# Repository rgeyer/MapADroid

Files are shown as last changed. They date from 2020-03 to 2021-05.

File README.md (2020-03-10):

# Description
This is a repository for all of resources that were used to build our local communities Pokemon scanner.

Primarily, this is the Map-A-Droid software, with some minor modifications, a docker compose file for our specific setup, and finally a 3d printed, rack mountable case for holding 16 of the Android TV boxes that are required for scanning.

This is an initial commit of VERY rough notes and resources, expect it to get more refined over time.

# BOM

|Qty|Item|Link|Cost Per|Total|Bulk Total|
|---|----|----|---|-----|---|
|16|A95X F1|https://www.amazon.com/Sawpy-Android-Smart-Quad-core-Cortex-A53/dp/B07PF271DF|$25.99|$415.84|$415.84|
|1|Meanwell 5v PSU|https://www.amazon.com/MEAN-WELL-LRS-350-5-Single-Switchable/dp/B0131V9TG0|$35.92|$35.92|$35.92|
|1|16 Channel 5v Relay Board|https://www.amazon.com/Organizer-16-Channel-Interface-Optocoupler-Arduino/dp/B07Y2X4F77|$13.98|$13.98|$13.98|
|16|DC Power Socket|https://www.amazon.com/gp/product/B01G6EB5U2/|$0.69|$11.04|$13.98|
|16|~1ft Length 22ga Power Wire|https://www.amazon.com/gp/product/B07SLBD1FY/|$0.15|$2.04|$15.00|
|1|Arduino ESP8266 NodeMCU|https://www.amazon.com/gp/product/B07HF44GBT/|$4.00|$4.00|$11.99|
|1|Waveshare Arduino IO Expansion Board 16ch|https://www.amazon.com/dp/B07P2H1NZG/|$7.95|$7.95|$7.95|
|1|1m Strip addressable LEDs|https://www.amazon.com/dp/B01CDTEJR0/|$21.88|$21.88|$21.88|
|1|Power Cable|https://www.amazon.com/gp/product/B01J4M3QDW|$3.59|$3.59|$17.95|
|3|18ga U Terminals|https://www.amazon.com/GFORTUN-Terminals-Insulated-Connector-22-16AWG/dp/B06XV8GLXJ/|$0.07|$0.21|$6.98|
|2|1kg PETG Filament|https://www.amazon.com/gp/product/B07PGYL6SV/|$18.33|$36.66|$54.99|
|2|80mm 5v cooling fan|https://www.amazon.com/dp/B0119SLG18/|$7.01|$14.02|$14.02|
|4|8 Position Dual Row Terminal Strip + Barrier Strip|https://www.amazon.com/dp/B07CLX1VW5/|$1.92|$7.66|$11.49|
|16|1ft Ethernet Patch Cables (CAT5 is fine, but impossible to find)|https://www.amazon.com/dp/B07CXPQ4SX/|$0.95|$15.20|$18.99|
|1|24 Port Ethernet switch|Ebay|~$60|~$60|~$60|
|1|IKEA Lack Side Table|https://www.ikea.com/us/en/p/lack-side-table-black-20011408/|$15|$15|$15|
|||||||
||Totals|||$663.11|$741.84|

# 3D Printed Parts

STLs in the `resources/ATVRackSTLs` directory.

Design 1, before optimization

|Qty|STL|Weight ea.|Weight Total|
|---|---|---|---|
|1|CabCenter|480g|480g|
|1|CabLeft|316g|316g|
|1|CabRight|316g|316g|
|16|Tray|18g|288g|
|2|ATVFrontLidBottom|14g|28g|
|2|ATVRearLidBottom|15g|30g|
|2|ATVFrontLidTop|12g|24g|
|2|ATVRearLidTop|53g|106g|
|1|PSUBracket|42g|42g|
|1|LidCenter|37g|37g|
||||1667g|

|Qty|STL|Weight ea.|Weight Total|Spool Before|Spool After|
|---|---|---|---|---|---|
|1|CabCenter|300g|300g|1240g|1067g|
|1|CabLeft|246g|246g|654g|464g2|
|1|CabRight|246g|246g|||
|16|Tray|9g|144g|||
|2|ATVFrontLidBottom|||||
|2|ATVRearLidBottom|||||
|2|ATVFrontLidTop|||||
|2|ATVRearLidTop|||||
|1|PSUBracket|||||
|1|LidCenter|||||
||||1203g|

# TODO

* Modify RocketMAD to use a public sprite set
  * https://github.com/whitewillem/PogoAssets
  * https://github.com/ZeChrales/PogoAssets

* Scheduled Maintenance
  * DB
    * (actually delete) select count(*) from pokemon where last_modified < DATE_SUB(NOW(), INTERVAL 72 HOUR);

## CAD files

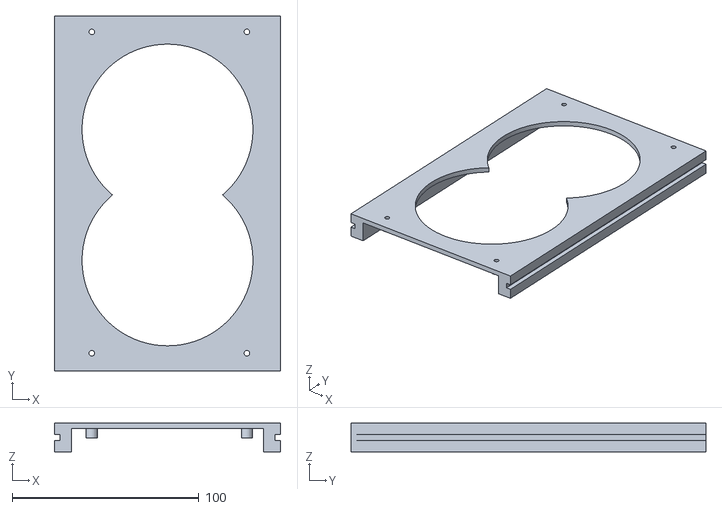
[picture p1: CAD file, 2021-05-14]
resources/ATVRackSTLs/RelayTray.stl
121.0 x 190.0 x 15.4

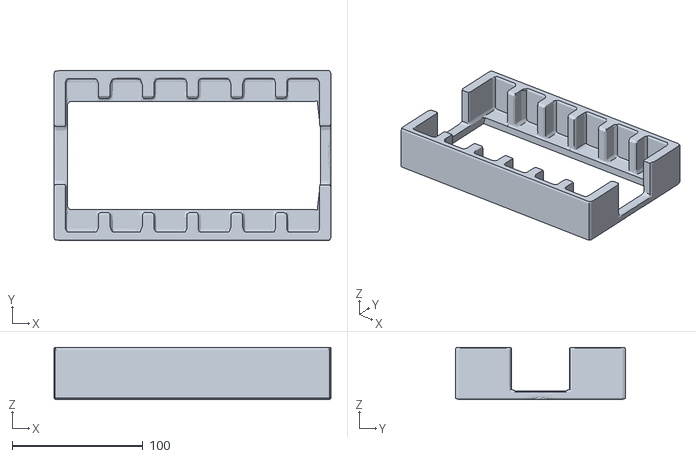
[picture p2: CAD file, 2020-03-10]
resources/atvstandf1.stl
212.2 x 130.4 x 40.0

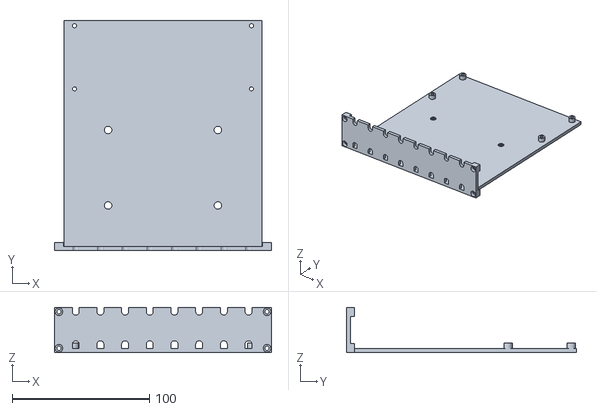
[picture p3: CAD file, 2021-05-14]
resources/ATVRackSTLs/BottomTerminalBlockTrayWith8chRelay.stl
158.2 x 168.0 x 33.2

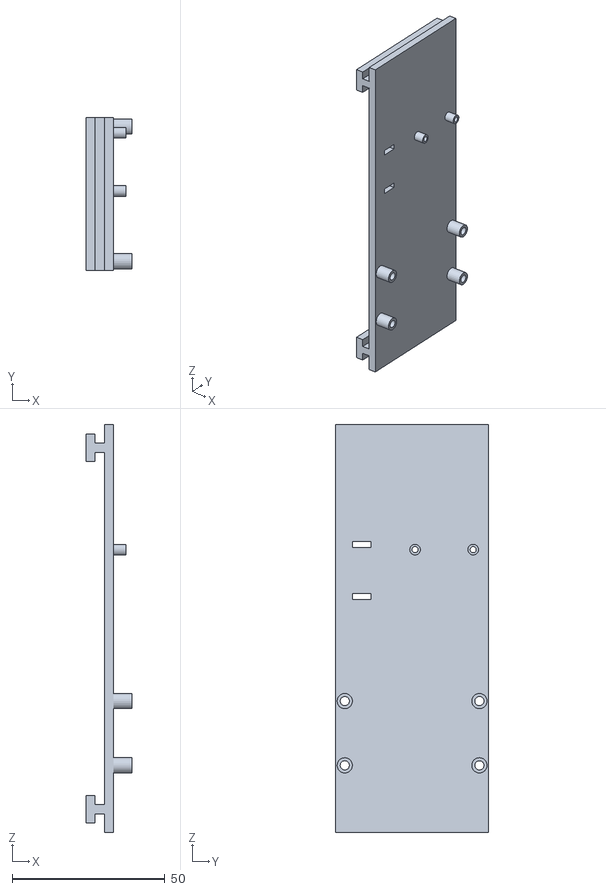
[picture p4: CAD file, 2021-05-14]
resources/ATVRackSTLs/IOBracketExternal.stl
15.1 x 50.0 x 133.4

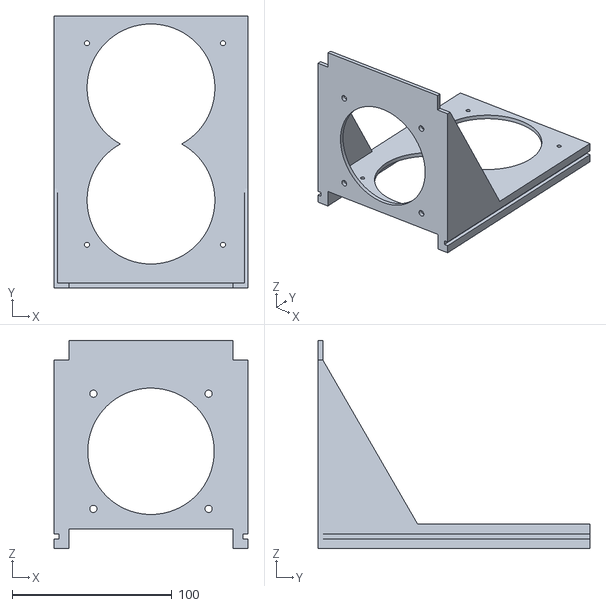
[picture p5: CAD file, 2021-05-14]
resources/ATVRackSTLs/200wPSUTray.stl
121.0 x 170.0 x 130.1

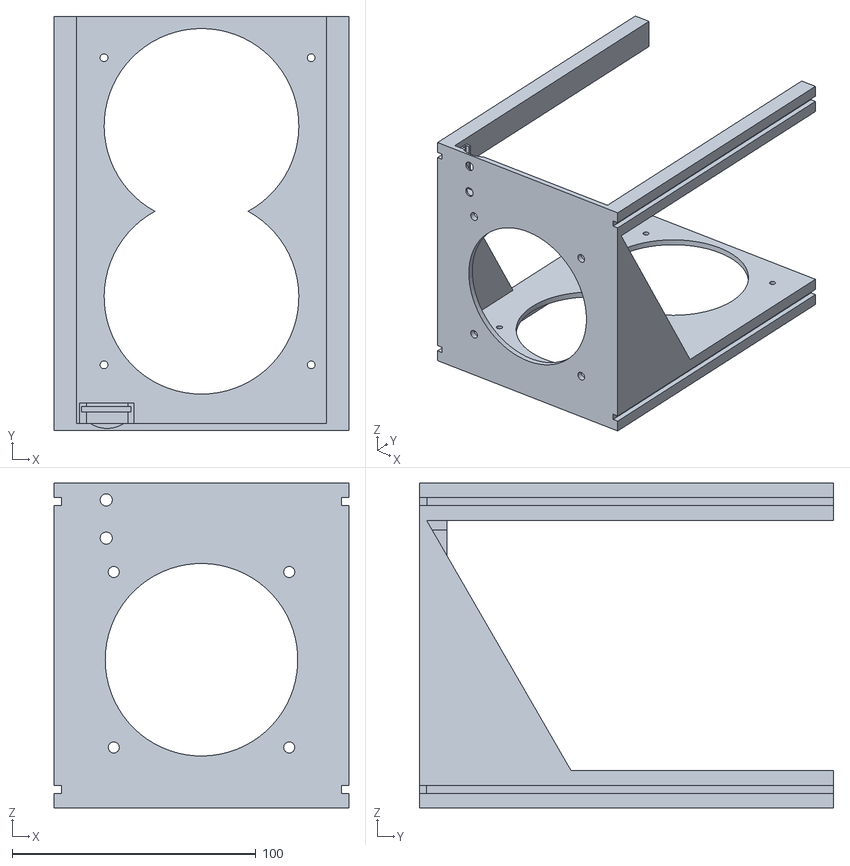
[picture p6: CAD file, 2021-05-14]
resources/ATVRackSTLs/200wPSUTray8chRelays.stl
121.0 x 170.0 x 133.4

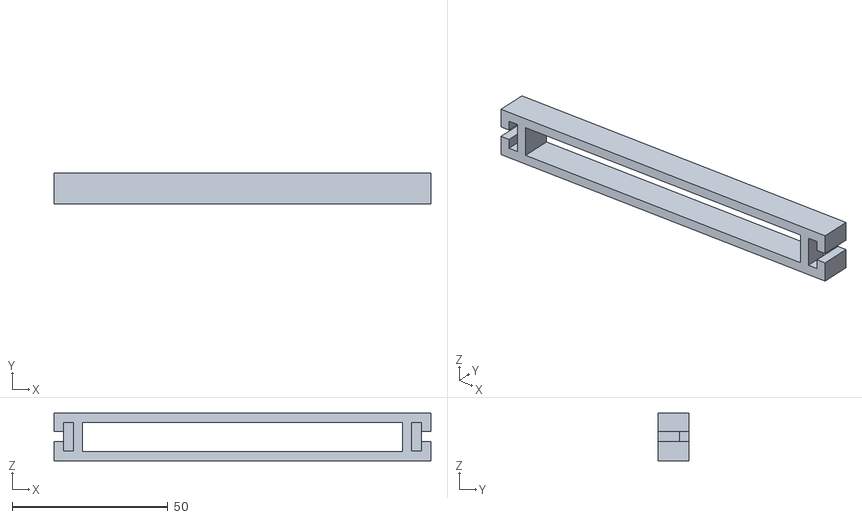
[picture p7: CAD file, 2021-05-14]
resources/ATVRackSTLs/SingleBridge.stl
121.0 x 10.0 x 15.4

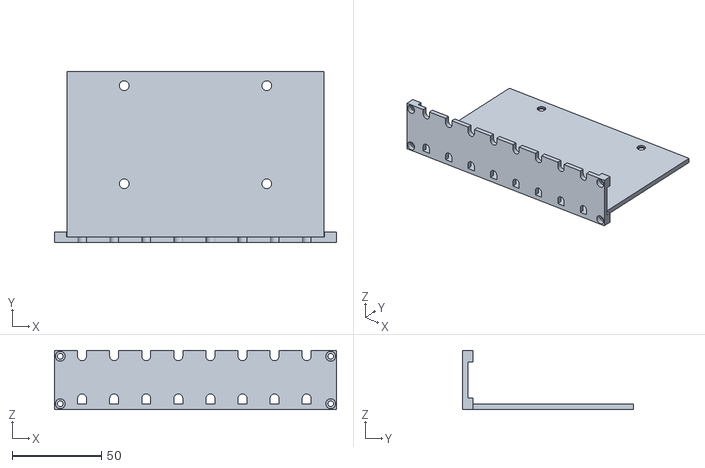
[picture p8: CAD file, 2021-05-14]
resources/ATVRackSTLs/BottomTerminalBlockTray.stl
158.2 x 96.0 x 33.2

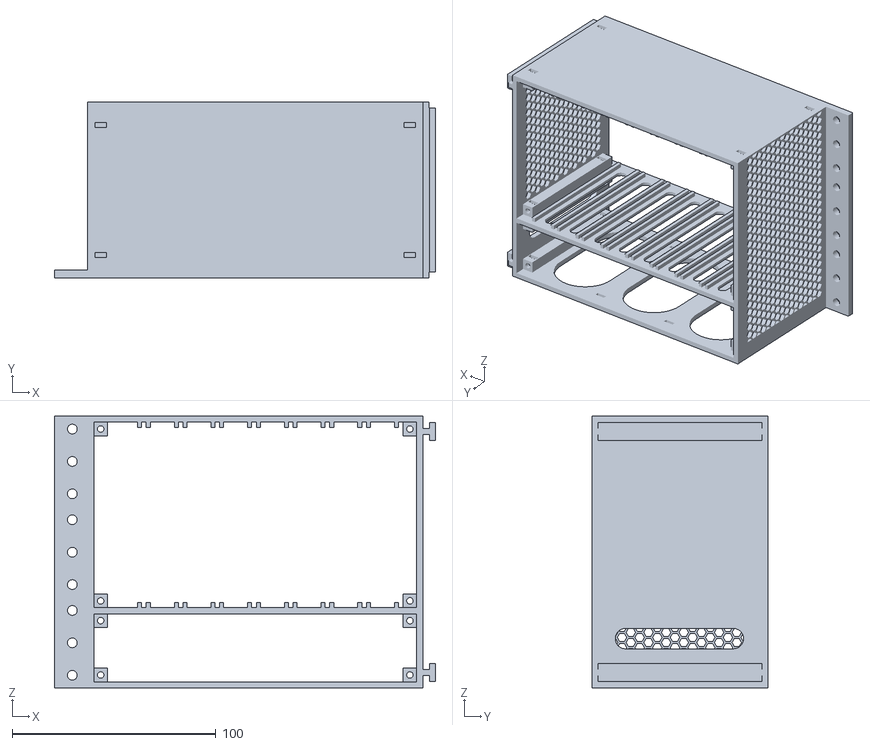
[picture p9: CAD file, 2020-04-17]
resources/ATVRackSTLs/CabLeft.stl
186.9 x 86.4 x 133.4

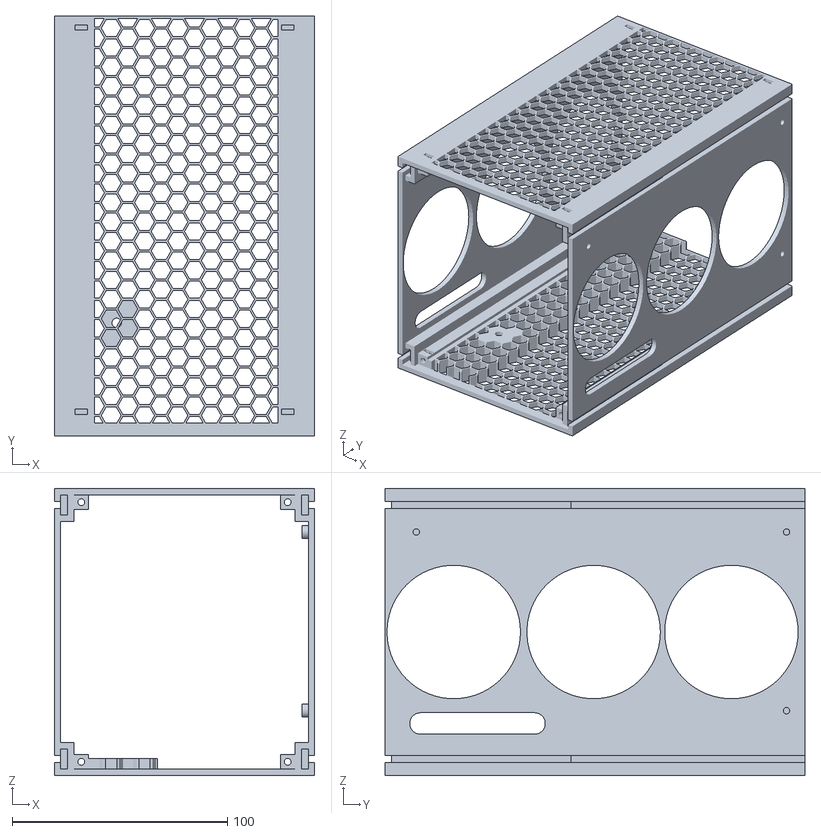
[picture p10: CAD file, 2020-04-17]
resources/ATVRackSTLs/CabCenter.stl
121.0 x 195.0 x 133.4

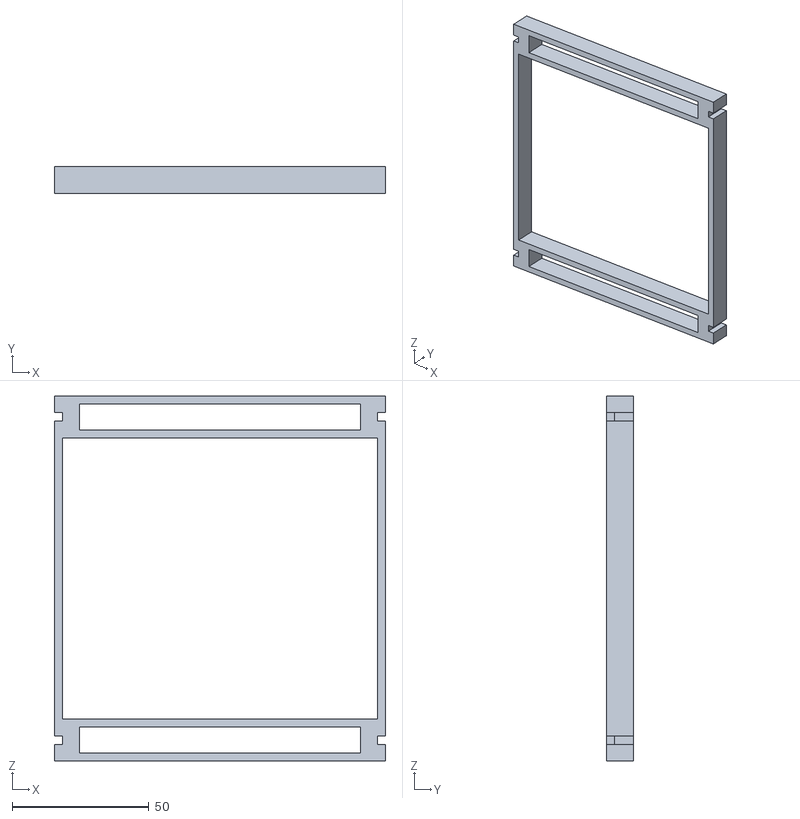
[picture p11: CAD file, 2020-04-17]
resources/ATVRackSTLs/CenterBridge.stl
121.0 x 10.0 x 133.4

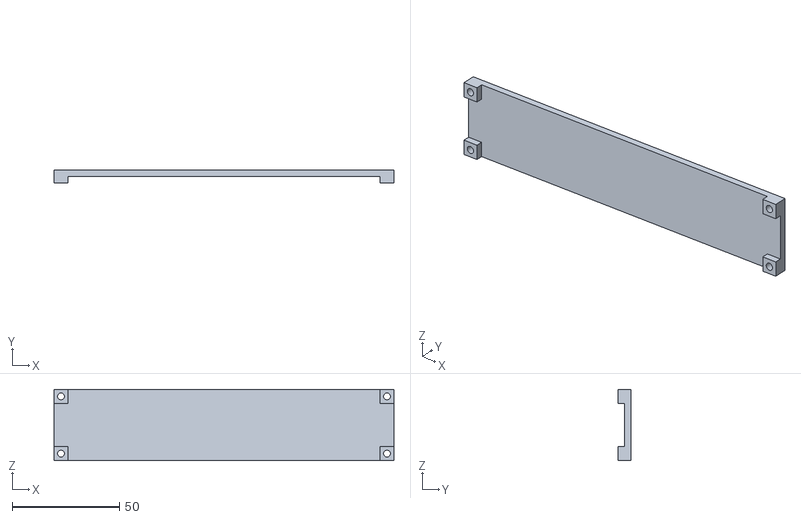
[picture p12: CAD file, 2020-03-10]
resources/ATVRackSTLs/ATVRearLidBottom.stl
158.2 x 6.00 x 33.2

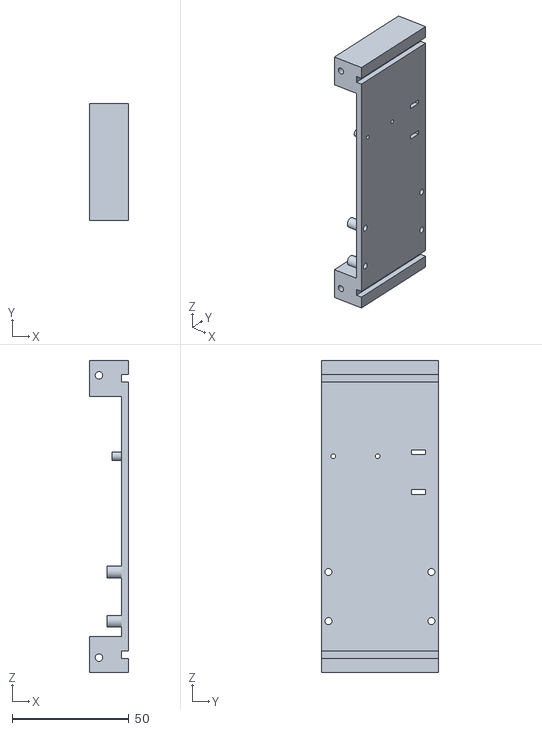
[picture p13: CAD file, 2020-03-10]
resources/ATVRackSTLs/IOBracket.stl
16.5 x 50.0 x 133.4

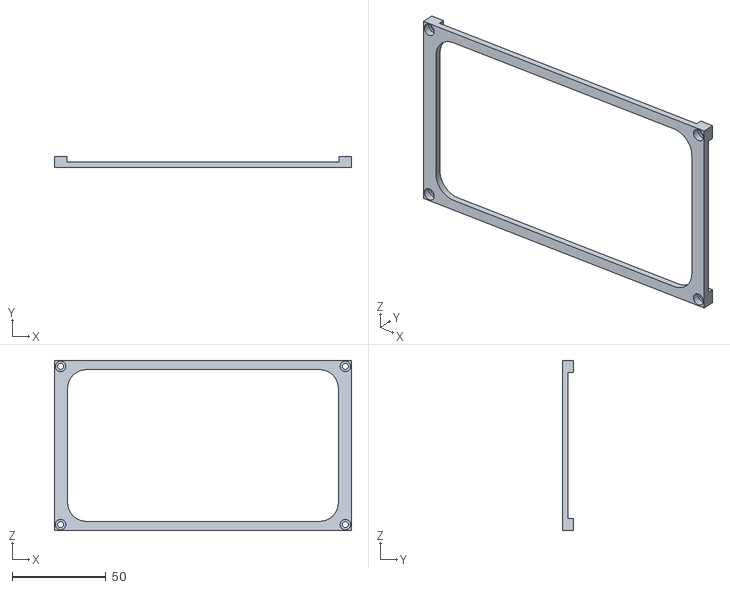
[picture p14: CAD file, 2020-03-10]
resources/ATVRackSTLs/ATVFrontLidTop.stl
158.2 x 6.00 x 90.8

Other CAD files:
resources/ATVRackSTLs/CabRight.stl
resources/ATVRackSTLs/PSUBracket.stl
resources/ATVRackSTLs/Tray.stl
resources/ATVRackSTLs/ATVFrontLidBottom.stl
resources/ATVRackSTLs/ATVRearLidTop.stl

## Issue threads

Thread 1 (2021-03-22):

Missing config.json

focusbbs, 2021-03-22:
Hi, the sample config.json i'am missing.
lg Peter

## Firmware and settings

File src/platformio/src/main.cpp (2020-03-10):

#define DEBUG_ESP_OTA
#define DEBUG_ESP_MDNS_RESPONDER

#include <ESP8266WiFi.h>
#include <ESPAsyncWebServer.h>
#include <WiFiClientSecure.h>
#include <MQTT.h>
#include <PubSubClient.h>
#include <ArduinoJson.h>
#include <FS.h>
#include <time.h>
#define emptyString String()

//Follow instructions from https://github.com/debsahu/ESP-MQTT-AWS-IoT-Core/blob/master/doc/README.md
//Enter values in secrets.h ▼
#include "secrets.h"
#include <ArduinoOTA.h>
#include <ESP8266mDNS.h>
#include "rgb.cpp"
// #include "madrack.cpp"

// MadRack madrack;

RackRGB rgb;

#if !(ARDUINOJSON_VERSION_MAJOR == 6 and ARDUINOJSON_VERSION_MINOR >= 7)
#error "Install ArduinoJson v6.7.0-beta or higher"
#endif

#include <Adafruit_MCP23017.h>
Adafruit_MCP23017 mcp;

const int MQTT_PORT = 8883;
const char MQTT_SUB_TOPIC[] = "$aws/things/" THINGNAME "/shadow/update/delta";
const char MQTT_PUB_TOPIC[] = "$aws/things/" THINGNAME "/shadow/update";

#ifdef USE_SUMMER_TIME_DST
uint8_t DST = 1;
#else
uint8_t DST = 0;
#endif

WiFiClientSecure net;

BearSSL::X509List cert(cacert);
BearSSL::X509List client_crt(client_cert);
BearSSL::PrivateKey key(privkey);

PubSubClient client(net);
AsyncWebServer server(80);

unsigned long lastMillis = 0;
time_t now;
time_t nowish = 1510592825;

void NTPConnect(void)
{
  Serial.print("Setting time using SNTP");
  configTime(TIME_ZONE * 3600, DST * 3600, "pool.ntp.org", "time.nist.gov");
  now = time(nullptr);
  while (now < nowish)
  {
    delay(500);
    Serial.print(".");
    now = time(nullptr);
  }
  Serial.println("done!");
  struct tm timeinfo;
  gmtime_r(&now, &timeinfo);
  Serial.print("Current time: ");
  Serial.print(asctime(&timeinfo));
}

void messageReceived(char *topic, byte *payload, unsigned int length)
{
  DynamicJsonDocument doc(1024);
  DeserializationError error = deserializeJson(doc, payload);

  if (error) {
    Serial.print(F("deserializeJson() failed: "));
    Serial.println(error.c_str());
  }

  uint16_t power = doc["state"]["power"];
  mcp.writeGPIOAB(power);
}

void pubSubErr(int8_t MQTTErr)
{
  if (MQTTErr == MQTT_CONNECTION_TIMEOUT)
    Serial.print("Connection tiemout");
  else if (MQTTErr == MQTT_CONNECTION_LOST)
    Serial.print("Connection lost");
  else if (MQTTErr == MQTT_CONNECT_FAILED)
    Serial.print("Connect failed");
  else if (MQTTErr == MQTT_DISCONNECTED)
    Serial.print("Disconnected");
  else if (MQTTErr == MQTT_CONNECTED)
    Serial.print("Connected");
  else if (MQTTErr == MQTT_CONNECT_BAD_PROTOCOL)
    Serial.print("Connect bad protocol");
  else if (MQTTErr == MQTT_CONNECT_BAD_CLIENT_ID)
    Serial.print("Connect bad Client-ID");
  else if (MQTTErr == MQTT_CONNECT_UNAVAILABLE)
    Serial.print("Connect unavailable");
  else if (MQTTErr == MQTT_CONNECT_BAD_CREDENTIALS)
    Serial.print("Connect bad credentials");
  else if (MQTTErr == MQTT_CONNECT_UNAUTHORIZED)
    Serial.print("Connect unauthorized");
}

void connectToMqtt(bool nonBlocking = false)
{
  Serial.print("MQTT connecting ");
  while (!client.connected())
  {
    if (client.connect(THINGNAME))
    {
      Serial.println("connected!");
      if (!client.subscribe(MQTT_SUB_TOPIC))
        pubSubErr(client.state());
    }
    else
    {
      Serial.print("failed, reason -> ");
      pubSubErr(client.state());
      if (!nonBlocking)
      {
        Serial.println(" < try again in 5 seconds");
        delay(5000);
      }
      else
      {
        Serial.println(" <");
      }
    }
    if (nonBlocking)
      break;
  }
}

void connectToWiFi(String init_str)
{
  if (init_str != emptyString)
    Serial.print(init_str);
  while (WiFi.status() != WL_CONNECTED)
  {
    Serial.print(".");
    delay(1000);
  }
  if (init_str != emptyString) {
    Serial.print("IP address: ");
    Serial.println(WiFi.localIP());
  }
}

void checkWiFiThenMQTT(void)
{
  connectToWiFi("Checking WiFi");
  connectToMqtt();
}

unsigned long previousMillis = 0;
const long interval = 5000;

void checkWiFiThenMQTTNonBlocking(void)
{
  connectToWiFi(emptyString);
  if (millis() - previousMillis >= interval && !client.connected())
  {
    previousMillis = millis();
    connectToMqtt(true);
  }
}

void checkWiFiThenReboot(void)
{
  connectToWiFi("Checking WiFi");
  Serial.print("Rebooting");
  ESP.restart();
}

void sendData(void)
{
  DynamicJsonDocument jsonBuffer(JSON_OBJECT_SIZE(3) + 100);
  JsonObject root = jsonBuffer.to<JsonObject>();
  JsonObject state = root.createNestedObject("state");
  JsonObject state_reported = state.createNestedObject("reported");
  state_reported["power"] = mcp.readGPIOAB();
  // state_reported["value"] = random(100);  
  Serial.printf("Sending  [%s]: ", MQTT_PUB_TOPIC);
  serializeJson(root, Serial);
  Serial.println();
  char shadow[measureJson(root) + 1];
  serializeJson(root, shadow, sizeof(shadow));
  if (!client.publish(MQTT_PUB_TOPIC, shadow, false))
    pubSubErr(client.state());
}

void setup()
{
  Serial.begin(115200);
  delay(5000);

  // Serial.println("Setup Began");
  // madrack.begin(D3);
  // Serial.println("madrack finished");
  
  rgb.begin();
  mcp.begin(0x27);
  for (int i=0; i < 16; i++) {
    mcp.pinMode(i, OUTPUT);
    mcp.pullUp(i, HIGH);    
    mcp.digitalWrite(i, HIGH);
  } 

  if(!SPIFFS.begin()) {
    Serial.println("Unable to start SPIFFS");
  }

  Serial.println();
  Serial.println();
  WiFi.hostname(THINGNAME);
  WiFi.mode(WIFI_STA);
  WiFi.begin(ssid, pass);
  connectToWiFi(String("Attempting to connect to SSID: ") + String(ssid));

  NTPConnect();
  
  net.setTrustAnchors(&cert);
  net.setClientRSACert(&client_crt, &key);

  client.setServer(MQTT_HOST, MQTT_PORT);
  client.setCallback(messageReceived);

  connectToMqtt();

  // OTA Stuff
  ArduinoOTA.onStart([]() {
    String type;
    if (ArduinoOTA.getCommand() == U_FLASH)
    {
      type = "sketch";
    }
    else
    { // U_FS
      type = "filesystem";
    }

    // NOTE: if updating FS this would be the place to unmount FS using FS.end()
    Serial.println("Start updating " + type);
  });
  ArduinoOTA.onEnd([]() {
    Serial.println("\nEnd");
  });
  ArduinoOTA.onProgress([](unsigned int progress, unsigned int total) {
    Serial.printf("Progress: %u%%\r", (progress / (total / 100)));
  });
  ArduinoOTA.onError([](ota_error_t error) {
    Serial.printf("Error[%u]: ", error);
    if (error == OTA_AUTH_ERROR)
    {
      Serial.println("Auth Failed");
    }
    else if (error == OTA_BEGIN_ERROR)
    {
      Serial.println("Begin Failed");
    }
    else if (error == OTA_CONNECT_ERROR)
    {
      Serial.println("Connect Failed");
    }
    else if (error == OTA_RECEIVE_ERROR)
    {
      Serial.println("Receive Failed");
    }
    else if (error == OTA_END_ERROR)
    {
      Serial.println("End Failed");
    }
  });
  ArduinoOTA.setPort(8266);
  ArduinoOTA.setHostname(THINGNAME);
  ArduinoOTA.begin();

  server.on("/", HTTP_GET, [](AsyncWebServerRequest *request) {
    request->send(SPIFFS, "/hello.html");
  });

  server.on("/", HTTP_POST, [](AsyncWebServerRequest *request) {
    mcp.writeGPIOAB(65534);
    request->send(SPIFFS, "/hello.html");
  });
  server.begin();
  
  MDNS.addService("http", "tcp", 80);
}

void loop()
{
  now = time(nullptr);
  if (!client.connected())
  {
    checkWiFiThenMQTT();
    //checkWiFiThenMQTTNonBlocking();
    //checkWiFiThenReboot();
  }
  else
  {
    client.loop();
    if (millis() - lastMillis > 5000)
    {
      lastMillis = millis();
      sendData();
      rgb.update();
    }    
  }
  ArduinoOTA.handle();
}

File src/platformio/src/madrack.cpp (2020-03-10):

// #include <FS.h>
// #include <Arduino.h>
// #include <ArduinoJson.h>
// #include <ESP8266WiFi.h>
// #include <ESP8266mDNS.h>
// #include <ESPAsyncWebServer.h>

// class MadRack {
//     private:
//     AsyncWebServer *_server;
//     bool _configured = false;
//     uint8_t _reset_pin;
//     String _config_file_path = "config.json";
//     const char* _name;
//     const char* _wifi_ssid;
//     const char* _wifi_pass;
//     const char* _iot_host;
//     const char* _iot_cacert;
//     const char* _iot_client_cert;
//     const char* _iot_key;

//     bool _readConfig() {
//         File configFile = SPIFFS.open(_config_file_path, "r");
//         if(!configFile) {
//             Serial.println("Unable to open config file.");
//             return false;
//         }

//         size_t size = configFile.size();
//         std::unique_ptr<char []> buf(new char[size]);
//         configFile.readBytes(buf.get(), size);

//         DynamicJsonDocument doc(size);
//         auto error = deserializeJson(doc, buf.get());
//         if (error) {
//             Serial.println("Unable to deserialize config file.");
//             return false;
//         }

//         _name = doc["name"];
//         _wifi_ssid = doc["wifi_ssid"];
//         _wifi_pass = doc["wifi_pass"];
//         _iot_host = doc["iot_host"];
//         _iot_cacert = doc["iot_cacert"];
//         _iot_client_cert = doc["iot_client_cert"];
//         _iot_key = doc["iot_key"];

//         return true;
//     }

//     void _configMode() {
//         WiFi.mode(WIFI_AP);
//         const char apname[] = "MADRack-" + ESP.getChipId();
//         Serial.println("Creating softAP with name " + apname);
//         WiFi.softAP(apname);
//         _server->on("/", HTTP_GET, [](AsyncWebServerRequest *request) {
//             request->send(200, "text/plain", "Setup Mode");
//         });

//         Serial.println("AP IP Address: " + WiFi.softAPIP().toString());
//     }

//     void _connectToWiFi() {

//     }

//     public:
//     MadRack() {
//         _server = new AsyncWebServer(80);
//     }

//     bool begin(uint8_t reset_pin) {
//         Serial.println("Heller?");
//         if (!SPIFFS.begin()) {
//             Serial.println("Unable to start SPIFFS");
//         }
//         _reset_pin = reset_pin;
//         // Setup the reset pin.
//         pinMode(_reset_pin, INPUT_PULLUP);
//         Serial.println("Pins all setup");

//         if(_readConfig()) {
//             WiFi.hostname(_name);
//             WiFi.mode(WIFI_STA);
//             WiFi.begin(_wifi_ssid, _wifi_pass);
//             Serial.println(String("Attempting to connect to SSID: ") + String(_wifi_ssid));
//             while (WiFi.status() != WL_CONNECTED)
//             {
//                 Serial.print(".");
//                 delay(1000);
//             }
//             Serial.println("");
//             Serial.print("IP address: ");
//             Serial.println(WiFi.localIP());

//             MDNS.addService("http", "tcp", 80);
//         } else {
//             _configMode();
//         }

//         Serial.println("Starting webserver");
//         _server->serveStatic("/fs", SPIFFS, "/");
//         _server->begin();
//         Serial.println("Server Started");
//         return true;
//     }

//     void loop() {
//         if(!_configured || digitalRead(_reset_pin) == LOW) {
//             // Reset
//         }
//     }
// };

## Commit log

2020-04-17 Added center STLs, and updated left/right cabinets
    [CabCenter.stl, CabLeft.stl, CabRight.stl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]
2021-05-14 STLs for new components and updates to existing
    [200wPSUTray.stl, 200wPSUTray8chRelays.stl, ATVFrontLidBottom.stl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]
